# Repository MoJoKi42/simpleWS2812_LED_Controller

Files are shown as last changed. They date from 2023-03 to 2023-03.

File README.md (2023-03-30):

# simpleWS2812_LED_Controller
WS2812 LED Controller with AVR µC and 5V Buck-Converter

<ins>Software/µC:</ins>
- **ATMega328P-AU**
- 8 different color effects
- see "AVR_Code" for code and fuse setting

<ins>Hardware:</ins>
- 12V Input
- 5V Output
- max. 5m strip length

finished Board and construction with case:
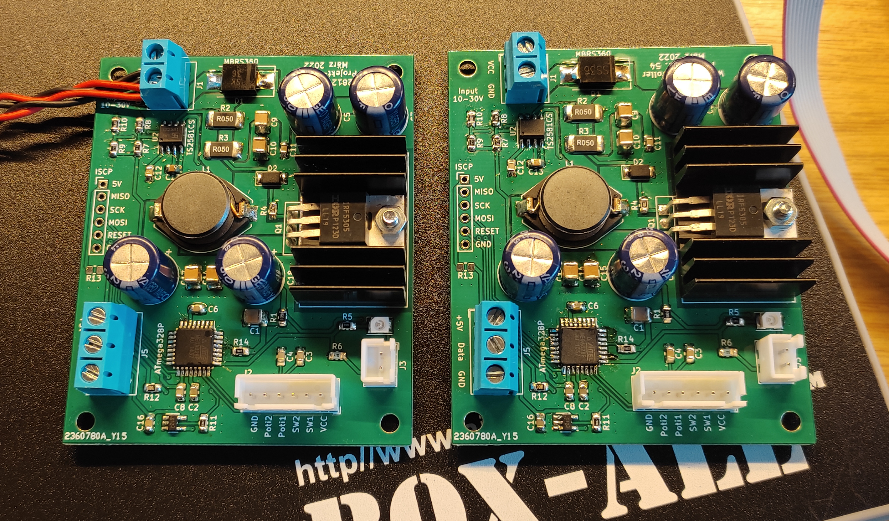
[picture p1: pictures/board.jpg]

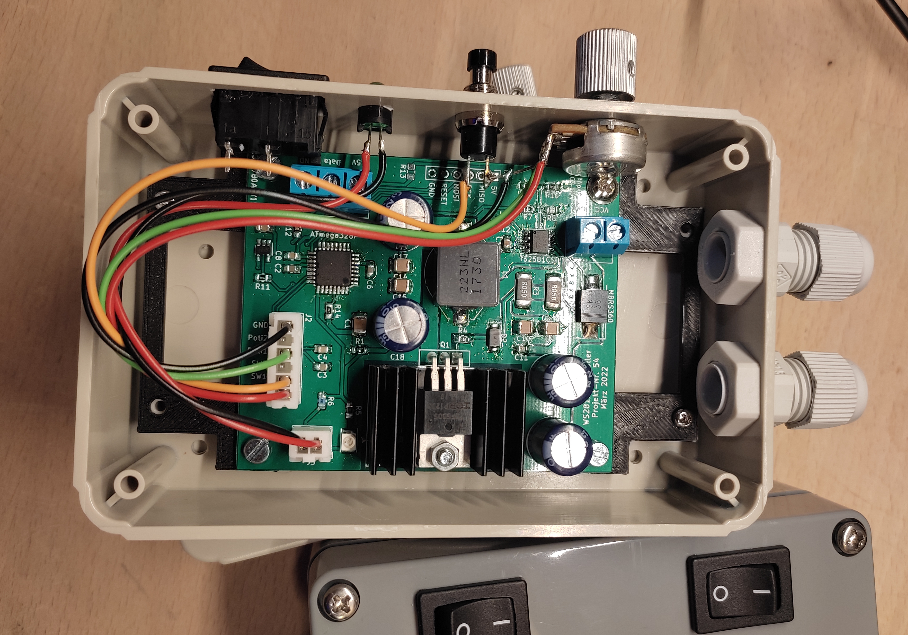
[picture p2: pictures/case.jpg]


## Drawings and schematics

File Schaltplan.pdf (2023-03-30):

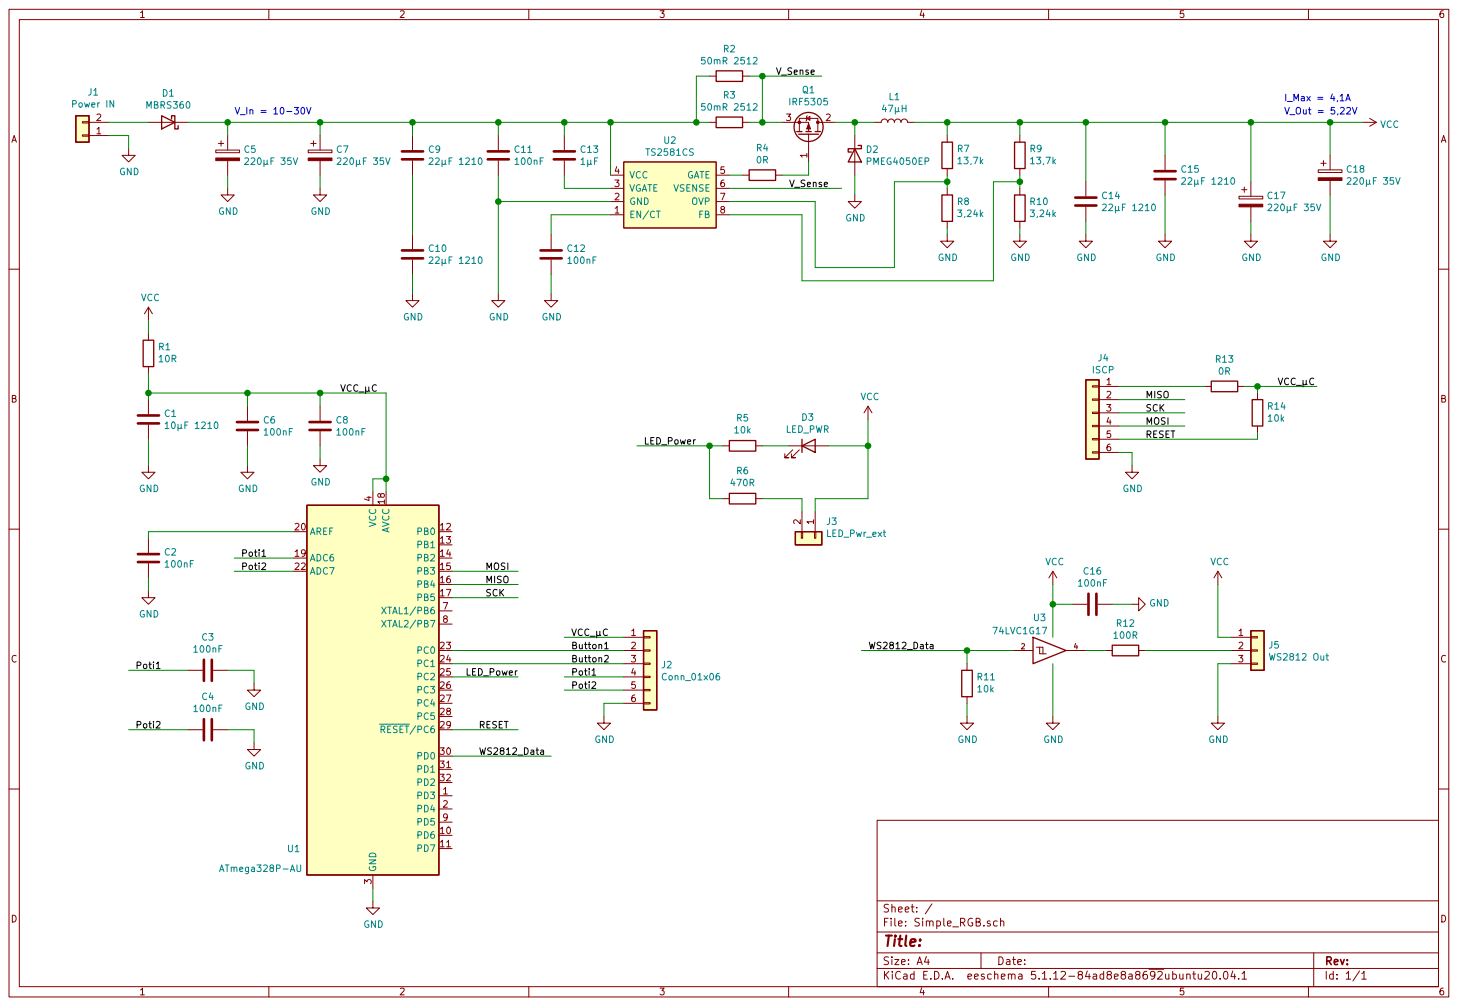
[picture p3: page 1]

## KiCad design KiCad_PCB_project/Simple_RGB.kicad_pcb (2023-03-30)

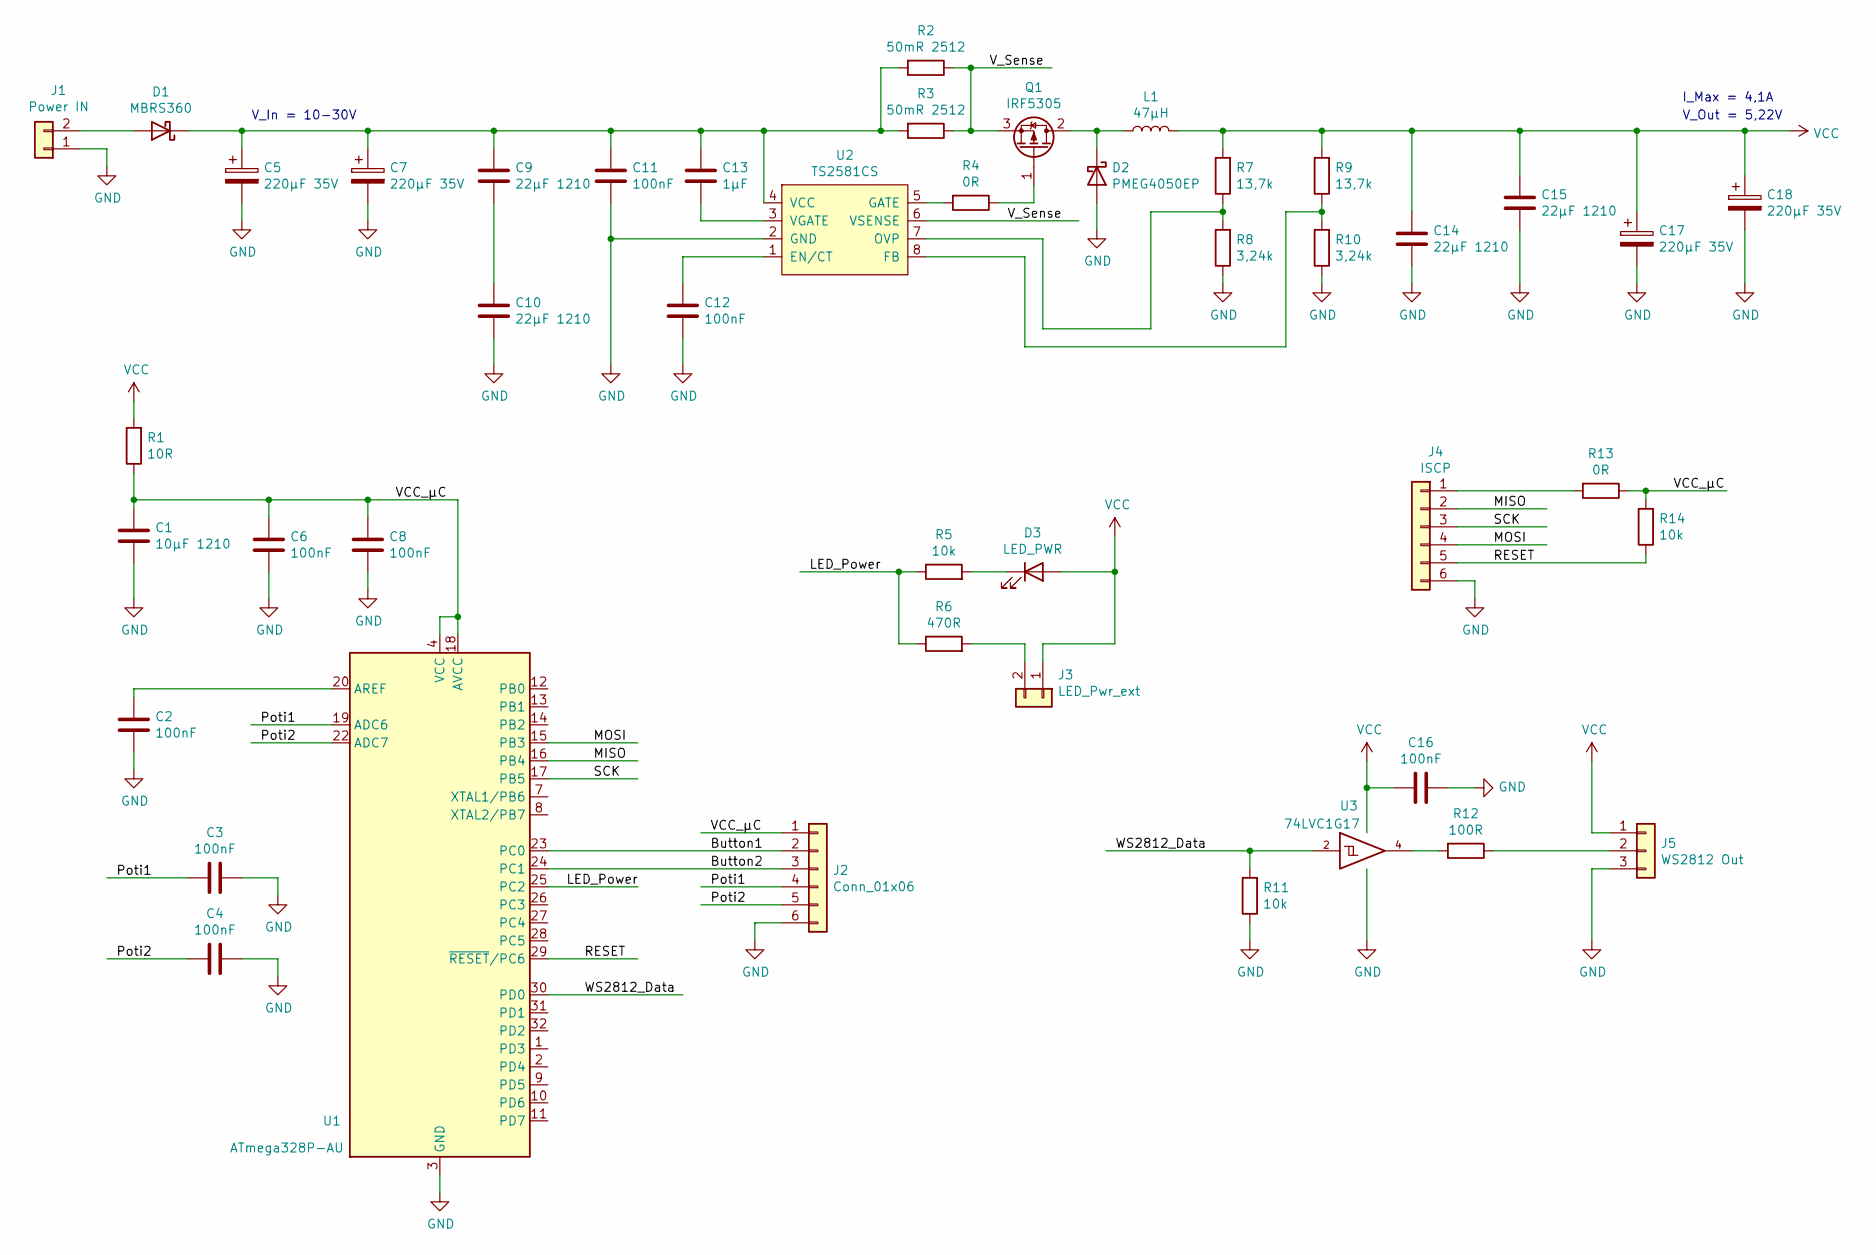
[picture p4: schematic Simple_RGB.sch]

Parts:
C1: 10µF 1210; C_1210_3225Metric_Pad1.33x2.70mm_HandSolder
C2, C3, C4, C6, C8, C11, C12, C16: 100nF; C_0805_2012Metric_Pad1.18x1.45mm_HandSolder
C5, C7, C17, C18: 220µF 35V; CP_Radial_D10.0mm_P5.00mm
C9, C10, C14, C15: 22µF 1210; C_1210_3225Metric_Pad1.33x2.70mm_HandSolder
C13: 1µF; C_0805_2012Metric_Pad1.18x1.45mm_HandSolder
D1: MBRS360; D_SMC_Handsoldering
D2: PMEG4050EP; D_SOD-128
D3: LED_PWR; LED_PLCC-2
J1: Power IN; TerminalBlock_RND_205-00001_1x02_P5.00mm_Horizontal
J2: Conn_01x06; JST_XH_B6B-XH-A_1x06_P2.50mm_Vertical
J3: LED_Pwr_ext; JST_XH_B2B-XH-A_1x02_P2.50mm_Vertical
J4: ISCP; PinHeader_1x06_P2.54mm_Vertical
J5: WS2812 Out; TerminalBlock_RND_205-00002_1x03_P5.00mm_Horizontal
L1: 47µH; L_Fastron_PISR_Handsoldering
Q1: IRF5305; TO-220-3_Vertical
R1: 10R; R_0805_2012Metric_Pad1.20x1.40mm_HandSolder
R2, R3: 50mR 2512; R_2512_6332Metric_Pad1.40x3.35mm_HandSolder
R4, R13: 0R; R_0805_2012Metric_Pad1.20x1.40mm_HandSolder
R5, R11, R14: 10k; R_0805_2012Metric_Pad1.20x1.40mm_HandSolder
R6: 470R; R_0805_2012Metric_Pad1.20x1.40mm_HandSolder
R7, R9: 13,7k; R_0805_2012Metric_Pad1.20x1.40mm_HandSolder
R8, R10: 3,24k; R_0805_2012Metric_Pad1.20x1.40mm_HandSolder
R12: 100R; R_0805_2012Metric_Pad1.20x1.40mm_HandSolder
U1: ATmega328P-AU; TQFP-32_7x7mm_P0.8mm
U2: TS2581CS; SOP-8_3.9x4.9mm_P1.27mm
U3: 74LVC1G17; SOT-23-5_HandSoldering

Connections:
/Button1: J2.2, U1.23 (PC0)
/Button2: J2.3, U1.24 (PC1)
/LED_Power: R5.1, R6.1, U1.25 (PC2)
/MISO: J4.2, U1.16 (PB4)
/MOSI: J4.4, U1.15 (PB3)
/Poti1: C3.2, J2.4, U1.19 (ADC6)
/Poti2: C4.2, J2.5, U1.22 (ADC7)
/RESET: J4.5, R14.1, U1.29 (~RESET~/PC6)
/SCK: J4.3, U1.17 (PB5)
/VCC_µC: C1.1, C6.1, C8.1, J2.1, R1.1, R13.1, R14.2, U1.4 (VCC), U1.6 (VCC), U1.18 (AVCC)
/V_Sense: Q1.3 (S), R2.1, R3.1, U2.6 (VSENSE)
/WS2812_Data: R11.2, U1.30 (PD0), U3.2
GND: C1.2, C2.2, C3.1, C4.1, C5.2, C6.2, C7.2, C8.2, C10.2, C11.2, C12.2, C14.2, C15.2, C16.1, C17.2, C18.2, D2.2 (A), J1.1, J2.6, J4.6, J5.3, R8.1, R10.1, R11.1, U1.3 (GND), U1.5 (GND), U1.21 (GND), U2.2 (GND), U3.3 (GND)
unnamed: C2.1, U1.20 (AREF)
unnamed: C9.2, C10.1
unnamed: C5.1, C7.1, C9.1, C11.1, C13.1, D1.1 (K), R2.2, R3.2, U2.4 (VCC)
unnamed: C12.1, U2.1 (EN/CT)
unnamed: C13.2, U2.3 (VGATE)
unnamed: D1.2 (A), J1.2
unnamed: D2.1 (K), L1.1, Q1.2 (D)
unnamed: D3.1 (K), R5.2
unnamed: J3.2, R6.2
unnamed: J4.1, R13.2
unnamed: J5.2, R12.1
unnamed: Q1.1 (G), R4.1
unnamed: R4.2, U2.5 (GATE)
unnamed: R7.1, R8.2, U2.7 (OVP)
unnamed: R9.1, R10.2, U2.8 (FB)
unnamed: R12.2, U3.4
VCC: C14.1, C15.1, C16.2, C17.1, C18.1, D3.2 (A), J3.1, J5.1, L1.2, R1.2, R7.2, R9.2, U3.5 (VCC)

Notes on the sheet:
V_Out = 5,22V
V_In = 10-30V
I_Max = 4,1A

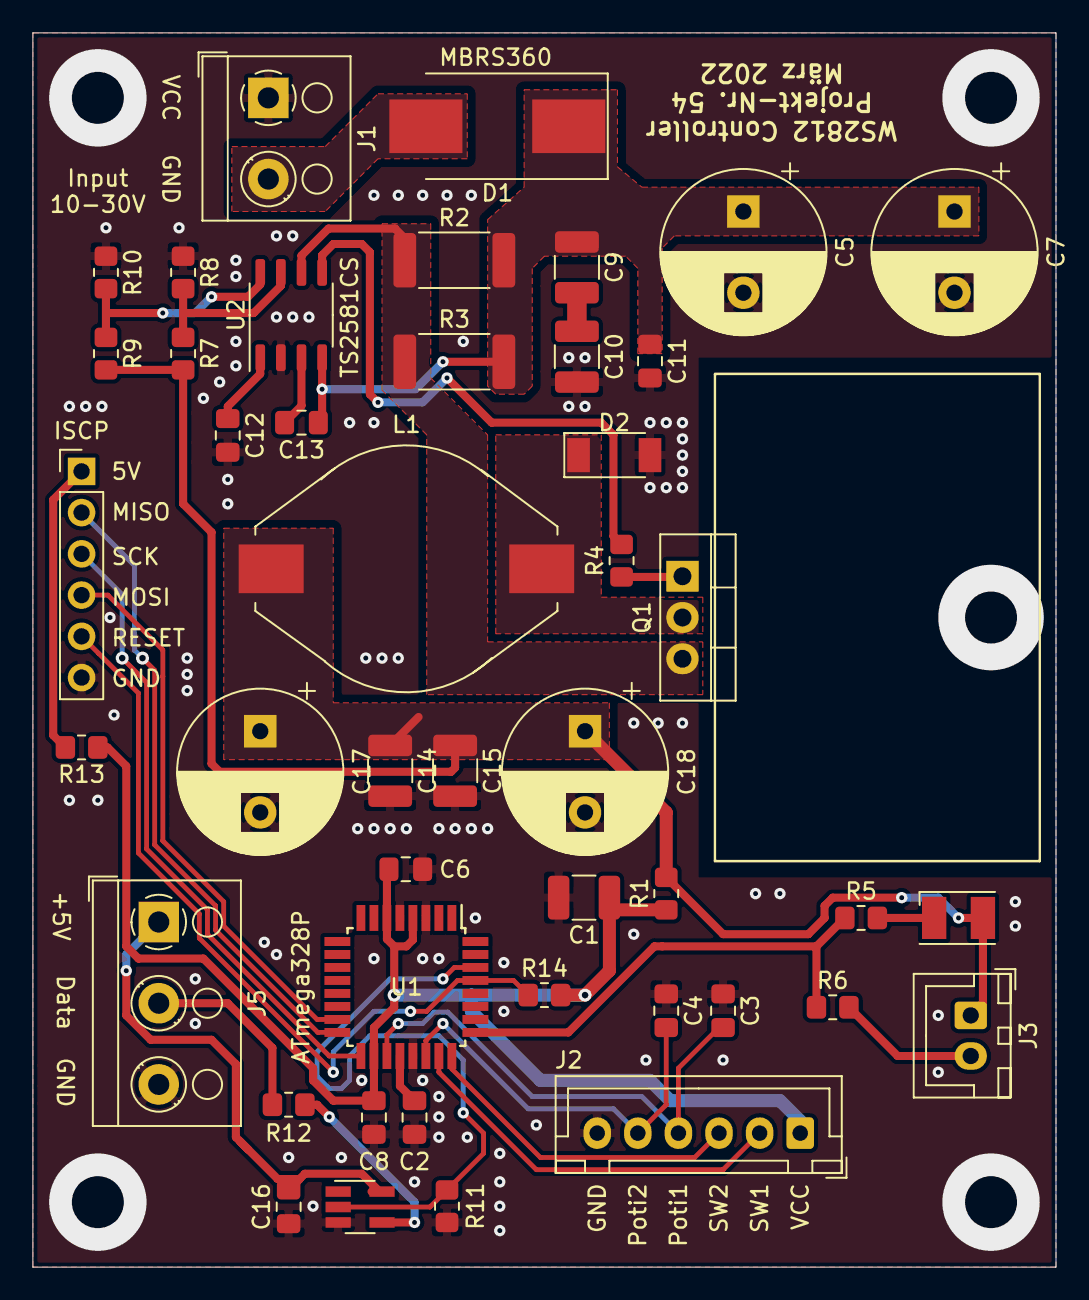
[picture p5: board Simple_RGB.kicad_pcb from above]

Board: 2 copper layers, 63.0 x 76.0 mm, 45 parts (0 on the bottom side), 30 nets.

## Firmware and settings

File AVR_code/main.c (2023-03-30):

#include <avr/io.h>
#include <util/delay.h>
#include <stdio.h>
#include <stdlib.h>
#include <math.h>
#include <time.h>
#include "adc.h"
#include "light_ws2812.h"
#include "hsv_fct.h"

// Befehle :
//
// -> Kompilieren
// make all
//
// -> Flashen
// avrdude -p m328p -c usbasp -e -U flash:w:main.hex
//
// -> Fuses schreiben
// avrdude -c usbasp -p m328p -U lfuse:w:0xE2:m -U hfuse:w:0xD9:m -U efuse:w:0xFF:m
//
// -> VS Code Include Pfad
// "/usr/lib/avr/include"
//


// Prototypen
void Timer2_Init(void);
struct cRGB hsv_to_cRGB(uint16_t hsv_color);


// globale Variablen + Makros
#define PWR_LED_on   PORTC &= ~(1<<PC2)
#define PWR_LED_off  PORTC |=  (1<<PC2)
#define BUTTON !(PINC & (1<<PINC0))

volatile uint32_t millis_counter = 0;
uint16_t helligkeit = 0;

// Aktualisierungsrate LEDs (ms)
uint8_t refresh_rate_LED = 20;

// LED Farben Zwischenspeicher (60 LEDs/m)
#define max_LEDs 300
struct cRGB LED[max_LEDs];


int main(void) {

    // In/Outputs
    PORTC |= (1<<PC0); // PullUp Button
    DDRC  |= (1<<PC2); // Output LED
    PWR_LED_on;

    // ADC initalisieren
    adc_init();
    
    // Timer initalisieren
    Timer2_Init();

    // LED Init
    struct cRGB temp;
    temp.r = 0; temp.g = 0; temp.b = 0;
    for (int i=0; i<max_LEDs; i++) {
        LED[i] = temp;
    }

    // Interrups aktivieren
    sei();
    
    // Effekt Merker
    uint8_t current_effect = 0;
    #define max_PROG 9
    // 0 = bewegter Regenbogen
    // 1 = Farbwechsel
    // 2 = rot
    // 3 = grün
    // 4 = blau
    // 5 = lila
    // 6 = grün-gelb
    // 7 = orange
    // 8 = weiß


    // Softstart
    static uint8_t softstart = 1;

    while(1) {
        
        // ADC auslesen
        helligkeit = (uint16_t)(adc_read_avg(6, 15));
        float helligkeit_float = (float)helligkeit / 1023.0;
        uint8_t hell_8bit = helligkeit/4;
        
        
        // Taster abfragen
        static uint32_t time_button = 0;
        if (BUTTON && millis_counter >= time_button && !softstart) {
            current_effect++;
            if (current_effect >= max_PROG)
                current_effect = 0;
            time_button = millis_counter + 150;
        }
        
        // hsv_val Inkrement
        static uint32_t time_hsv_val = 0;
        static uint16_t hsv_val = 0;
        if (millis_counter >= time_hsv_val) {
            hsv_val++;
            if (hsv_val >= 360)
                hsv_val = 0;
            if (current_effect == 0)
                time_hsv_val = millis_counter + 15; // etwas schneller für den Regenbogen Effekt
            else
                time_hsv_val = millis_counter + 50;
        }
        
        
        /////////////////////////////////
        // 0 Regenbogen Effekt
        /////////////////////////////////
        if(current_effect == 0) {
            for (uint16_t i=0; i<max_LEDs; i++) {
                
                // Berechne passenden HSV Wert
                uint32_t offset = ((uint32_t)i * (uint32_t)360) / (uint32_t)max_LEDs;
                offset = offset + hsv_val;
                offset = offset % 360;
                
                // Neue LED Farbwerte schreiben
                LED[i].r = ((uint16_t)HSV_to_Red(offset) * (uint16_t)hell_8bit) >> 8;
                LED[i].g = ((uint16_t)HSV_to_Green(offset) * (uint16_t)hell_8bit) >> 8;
                LED[i].b = ((uint16_t)HSV_to_Blue(offset) * (uint16_t)hell_8bit) >> 8;
                
                if (softstart)
                    _delay_ms(5);
            }
        }
        
        /////////////////////////////////
        // 1 Farbwechsel Effekt
        /////////////////////////////////
        if(current_effect == 1) {
            for (uint16_t i=0; i<max_LEDs; i++) {
                LED[i].r = (float)HSV_to_Red(hsv_val) * helligkeit_float;
                LED[i].g = (float)HSV_to_Green(hsv_val) * helligkeit_float;
                LED[i].b = (float)HSV_to_Blue(hsv_val) * helligkeit_float;
            }
        }
        
        /////////////////////////////////
        // 2-7 Fixe Farben
        /////////////////////////////////
        if(current_effect >= 2 && current_effect <= 7) {
            
            // Farbe festlegen
            uint16_t color = 0;
            switch(current_effect) {
                case 2: color = 0;      break;  // rot
                case 3: color = 120;    break;  // grün
                case 4: color = 240;    break;  // blau
                case 5: color = 320;    break;  // lila
                case 6: color = 90;     break;  // grün-gelb
                case 7: color = 30;     break;  // orange
                default: break;
            }
                
            // Neue LED Farbwerte schreiben
            for (uint16_t i=0; i<max_LEDs; i++) {
                LED[i].r = (float)HSV_to_Red(color) * helligkeit_float;
                LED[i].g = (float)HSV_to_Green(color) * helligkeit_float;
                LED[i].b = (float)HSV_to_Blue(color) * helligkeit_float;
            }
        }
        
        
        /////////////////////////////////
        // 8 Weiß
        /////////////////////////////////
        if(current_effect == 8) {
            for (uint16_t i=0; i<max_LEDs; i++) {
                LED[i].r = 180 * helligkeit_float;
                LED[i].g = 180 * helligkeit_float;
                LED[i].b = 180 * helligkeit_float;
            }
        }
        
        // Softstart deaktivieren
        softstart = 0;
    }
}




// Timer2 Interrupt
ISR(TIMER2_OVF_vect) {
    
    // Millisekundenzähler inkrementieren
    millis_counter++;
    
    // LEDs aktualisieren
    static uint8_t time_LED_refresh = 0;
    time_LED_refresh++;
    if (time_LED_refresh >= refresh_rate_LED) {
        
        // Interrups deaktivieren
        //cli();
        
        // LEDs aktualisieren (~11ms für 300 LEDs)
        ws2812_setleds(LED, max_LEDs);
        
        // Interrups aktivieren
        time_LED_refresh = 0;
        //millis_counter += 10; // verpasste counts inkrementieren
        //sei();
    }
}

// Timer 2 initalisieren (für ms Zeitbasis)
void Timer2_Init(void) {
    TCCR2A = 0x00;                      // Normalmodus
    TCCR2B = (1<<CS21) | (1<<CS20);     // Prescaler = 64
    TIMSK2 = (1<<TOIE2);                // Timer0 overflow interrup enable
    TCNT2 =  6;                         // Vorladewert 6
}

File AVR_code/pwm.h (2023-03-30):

#include <avr/io.h>
#include <stdlib.h>

// Simple PWM Lib
// ACHTUNG: Die PWM1 Funktionen müssen noch getestet werden!!! evtl. passt es nicht
//          weil es 16 Bit Timer sind!

#define PWM0_N_1    (_BV(CS00))
#define PWM0_N_8    (_BV(CS01))
#define PWM0_N_64   (_BV(CS01)|_BV(CS00))
#define PWM0_N_256  (_BV(CS02))
#define PWM0_N_1024 (_BV(CS02)|_BV(CS00))

#define PWM1_N_1    (_BV(CS10))
#define PWM1_N_8    (_BV(CS11))
#define PWM1_N_64   (_BV(CS11)|_BV(CS10))
#define PWM1_N_256  (_BV(CS12))
#define PWM1_N_1024 (_BV(CS12)|_BV(CS10))


// Init
void pwm0_init(void);
void pwm1_init(void);

// Set frequency
void pwm0_set_frequency(uint32_t N);
void pwm1_set_frequency(uint32_t N);

// Set value
void pwm0_set_value(char output, uint8_t value);
void pwm1_set_value(char output, uint8_t value);






void pwm0_set_value(char output, uint8_t value) {
    if (output == 'A') {
        OCR0A = value;
        if (value == 0) { TCCR0A &= ~(1<<COM0A1); } else { TCCR0A |= (1<<COM0A1); }
    }
    if (output == 'B') {
        OCR0B = value;
        if (value == 0) { TCCR0A &= ~(1<<COM0B1); } else { TCCR0A |= (1<<COM0B1); }
    }
}

void pwm1_set_value(char output, uint8_t value) {
    if (output == 'A') {
        OCR1A = value;
        if (value == 0) { TCCR1A &= ~(1<<COM1A1); } else { TCCR1A |= (1<<COM1A1); }
    }
    if (output == 'B') {
        OCR1B = value;
        if (value == 0) { TCCR1A &= ~(1<<COM1B1); } else { TCCR1A |= (1<<COM1B1); }
    }
}

void pwm0_set_frequency(uint32_t N) {
    TCCR0B = (TCCR0B & ~((1<<CS02)|(1<<CS01)|(1<<CS00))) | N; // set prescaler
}

void pwm1_set_frequency(uint32_t N) {
    TCCR1B = (TCCR1B & ~((1<<CS12)|(1<<CS11)|(1<<CS10))) | N; // set prescaler
}

void pwm0_init(void) {
    OCR0A = 0;
    OCR0B = 0;
    TCCR0A   = (1<<WGM01)  | (1<<WGM00);
    TCCR0A	|= (1<<COM0A1) | (1<<COM0B1); // Enable OC0A + OC0B Output Pin
}

void pwm1_init(void) {
    OCR1A = 0;
    OCR1B = 0;
    TCCR1A	 = (1<<WGM11)  | (1<<WGM10);
    TCCR1A	|= (1<<COM1A1) | (1<<COM1B1); // Enable OC1A + OC1B Output Pin
}
